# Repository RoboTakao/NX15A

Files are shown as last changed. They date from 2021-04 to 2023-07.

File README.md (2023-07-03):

# NX15A
Summary:  
http://robotakao.web.fc2.com/NX15/e/index.html  

[Key Controll]  
&emsp;When controlling with the keyboard.  
  
&emsp;M5Atom sketch : nx15_rosserial_wifi.ino  
  
&emsp;roslaunch nx15a nx15a_simulation_rosserial.launch  
&emsp;rosrun nx15a nx15a_walk_ik.py  
  
[Blynk Controll]  
&emsp;When controlling with the Blynk.  
  
&emsp;M5Atom sketch : nx15_rosserial_wifi_blynk_BT.ino  
  
&emsp;roslaunch nx15a nx15a_simulation_rosserial.launch  
&emsp;rosrun nx15a nx15a_walk_ik_blynk.py  
  
[Wii Nunchunck Controll]  
&emsp;When controlling with the Wii controller (M5Atom).  
&emsp;Use of IMU.  
  
&emsp;M5Atom sketch  
&emsp;&emsp;For robot : nx15_rosserial_wifi_IMU.ino  
&emsp;&emsp;For wii controller : nx15_rosserial_wifi_wii.ino  
  
&emsp;roslaunch nx15a nx15a_simulation_rosserial_wii_imu.launch  
&emsp;rosrun nx15a nx15a_walk_ik_wii_imu.py  
  
[Ultra Sonic Dinstance Sensor with Wii Nunchunck Controll]  
&emsp;Ultra Sonic Distance Sensor use.  
&emsp;When controlling with the Wii controller (M5Atom).  
  
&emsp;M5Atom sketch  
&emsp;&emsp;For robot : nx15_rosserial_wifi_IMU_Sonic.ino  
&emsp;&emsp;For wii controller : nx15_rosserial_wifi_wii.ino  
  
&emsp;roslaunch nx15a nx15a_simulation_rosserial_wii_imu.launch  
&emsp;rosrun nx15a nx15a_walk_ik_wii_imu_distancw.py

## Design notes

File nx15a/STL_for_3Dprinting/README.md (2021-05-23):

# NX15A
Summary:
http://robotakao.jp/NX15/e/index.html

These STL files are NX15 quadruped robot models.
This robot is under development. If you use these, please do so at your own risk.

d4.5 holes are for M3 insart nut.
d3 holes are for M2 insart nut.
d1.8 holes are for M2 tapping screw.

Body_Cover01.stl 1
Body_Cover02.stl 1
BoxBottom.stl 1
BoxFront.stl 1
BoxLeft.stl 1
BoxRear.stl 1
BoxRight.stl 1
Head_Cover.stl 1
Leg_part01.stl 2
Leg_part02.stl 2
Lever.stl 4
Plate01.stl 1
ServoBracket01.stl 2
ServoBracket02.stl 2
ServoBracket03.stl 4
ServoBracket04.stl 1
ServoBracket05.stl 1
ServoHornLever.stl 4
Spacer.stl 4
Stopper.stl 1
Tail_Cover.stl

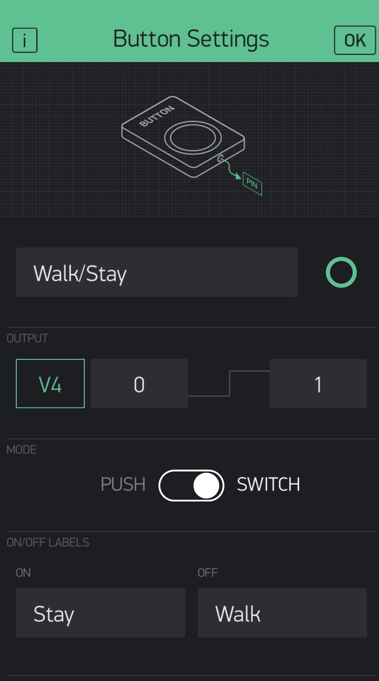
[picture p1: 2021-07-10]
nx15a/Blynk/Walk_Stay.jpeg

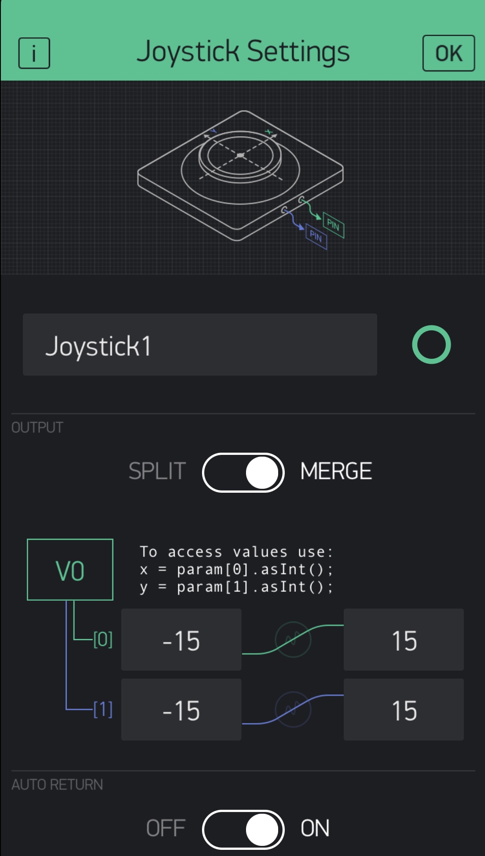
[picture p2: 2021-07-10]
nx15a/Blynk/Joystick1.jpeg

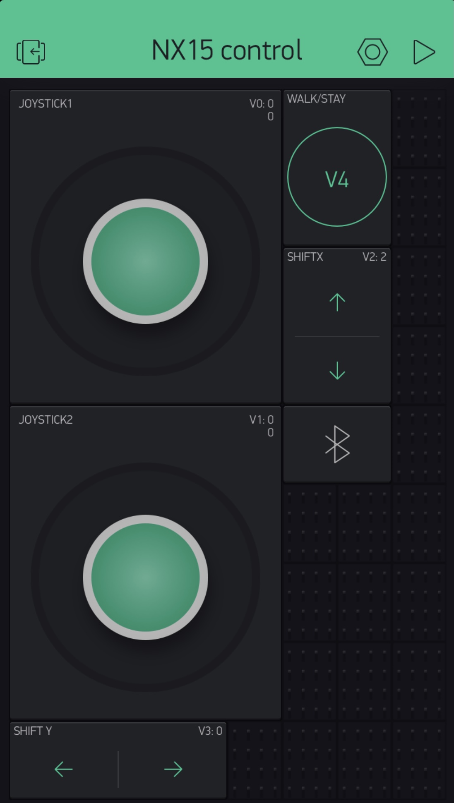
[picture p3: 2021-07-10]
nx15a/Blynk/Total.jpeg

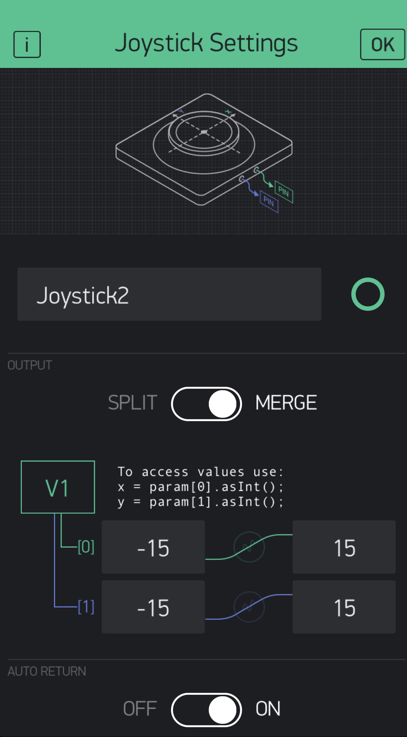
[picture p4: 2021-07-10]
nx15a/Blynk/Joystick2.jpeg

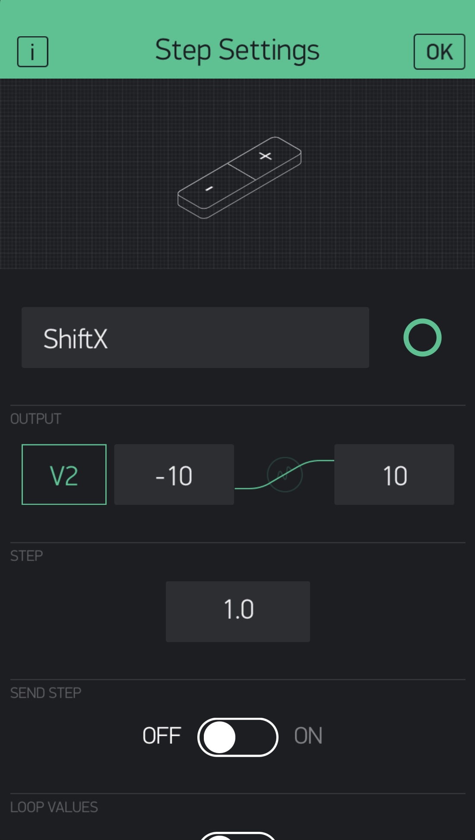
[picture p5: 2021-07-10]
nx15a/Blynk/ShiftX.jpeg

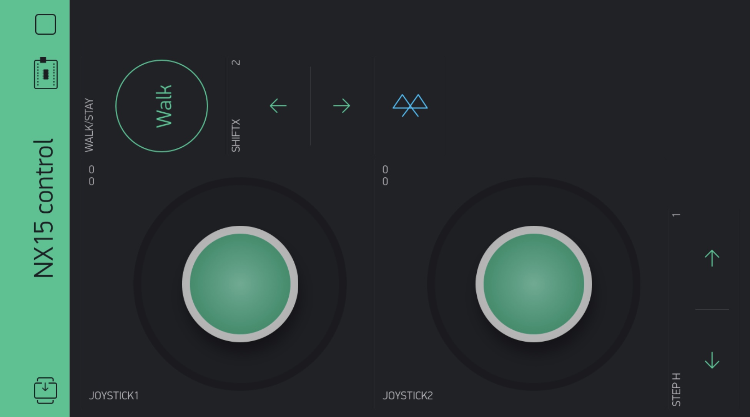
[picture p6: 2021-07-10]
nx15a/Blynk/NX15_controller.jpeg

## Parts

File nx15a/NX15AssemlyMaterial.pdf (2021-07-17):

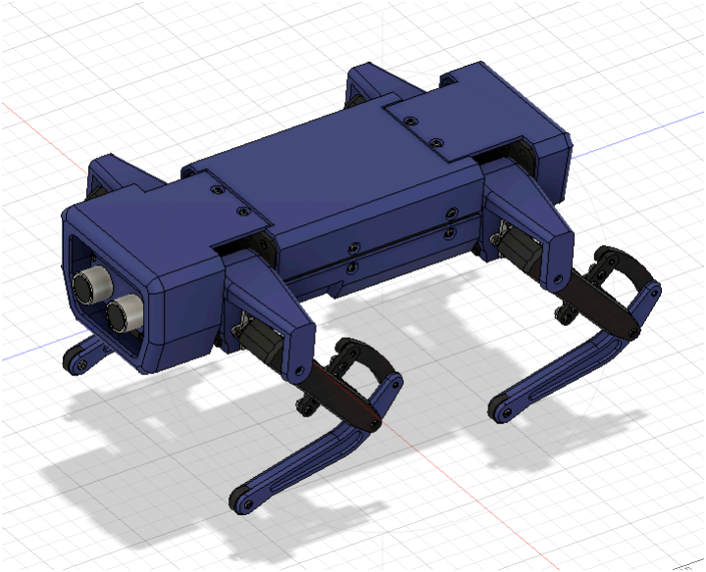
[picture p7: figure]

# Robo Takao 17.July.2021

# NX15 Quadruped Robot

# Assembly materials

# Leg Bottom (Left hand) x2

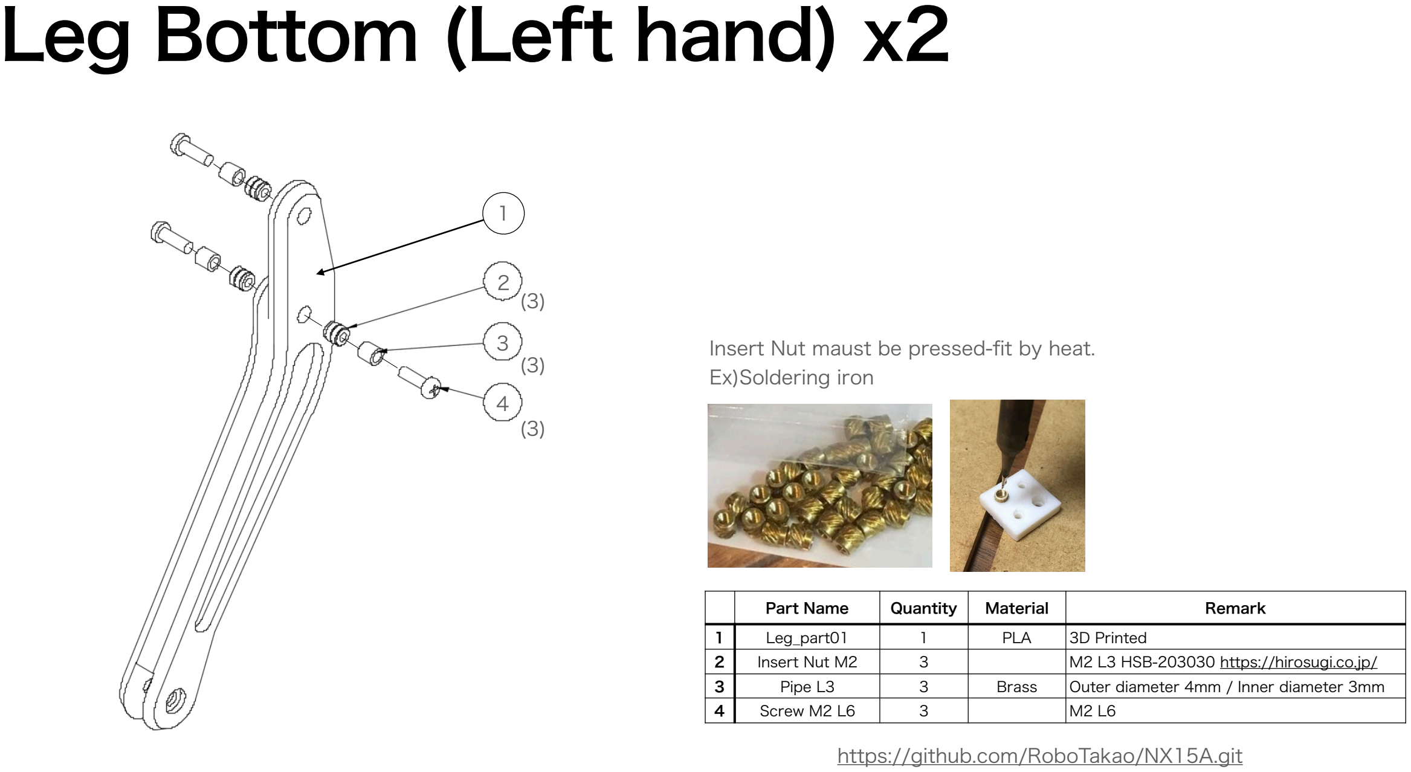
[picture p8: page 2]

| Part Name | Quantity | Material | Remark
1 | Leg_part01 | 1 | PLA | 3D Printed
2 | Insert Nut M2 | 3 | | M2 L3 HSB-203030 https://hirosugi.co.jp/
3 | Pipe L3 | 3 | Brass | Outer diameter 4mm / Inner diameter 3mm
4 | Screw M2 L6 | 3 | | M2 L6

1

2

3

4

## https://github.com/RoboTakao/NX15A.git

Insert Nut maust be pressed-fit by heat.

## Ex)Soldering iron

(3)

(3)

(3)

# Leg Bottom (Right hand) x2

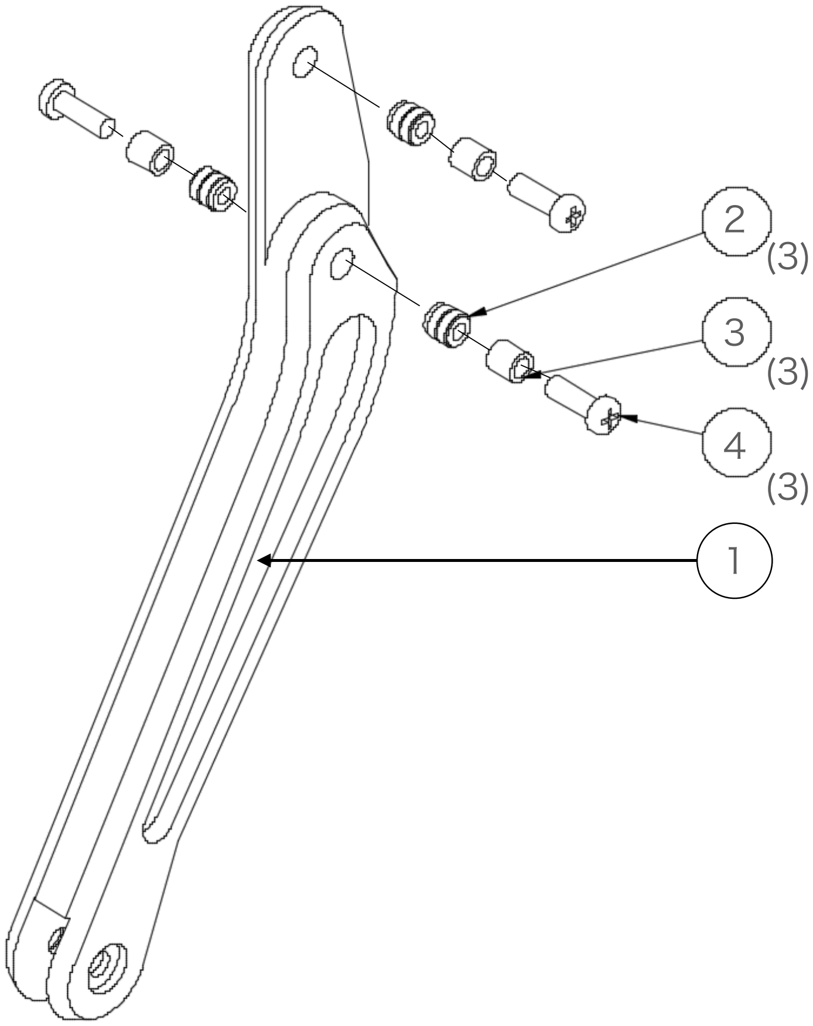
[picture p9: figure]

| Part Name | Quantity | Material | Remark
1 | Leg_part02 | 1 | PLA | 3D Printed
2 | Insert Nut M2 | 3 | | M2 L3 HSB-203030 https://hirosugi.co.jp/
3 | Pipe L3 | 3 | Brass | Outer diameter 4mm / Inner diameter 3mm
4 | Screw M2 L6 | 3 | | M2 L6

# Leg Middle x4

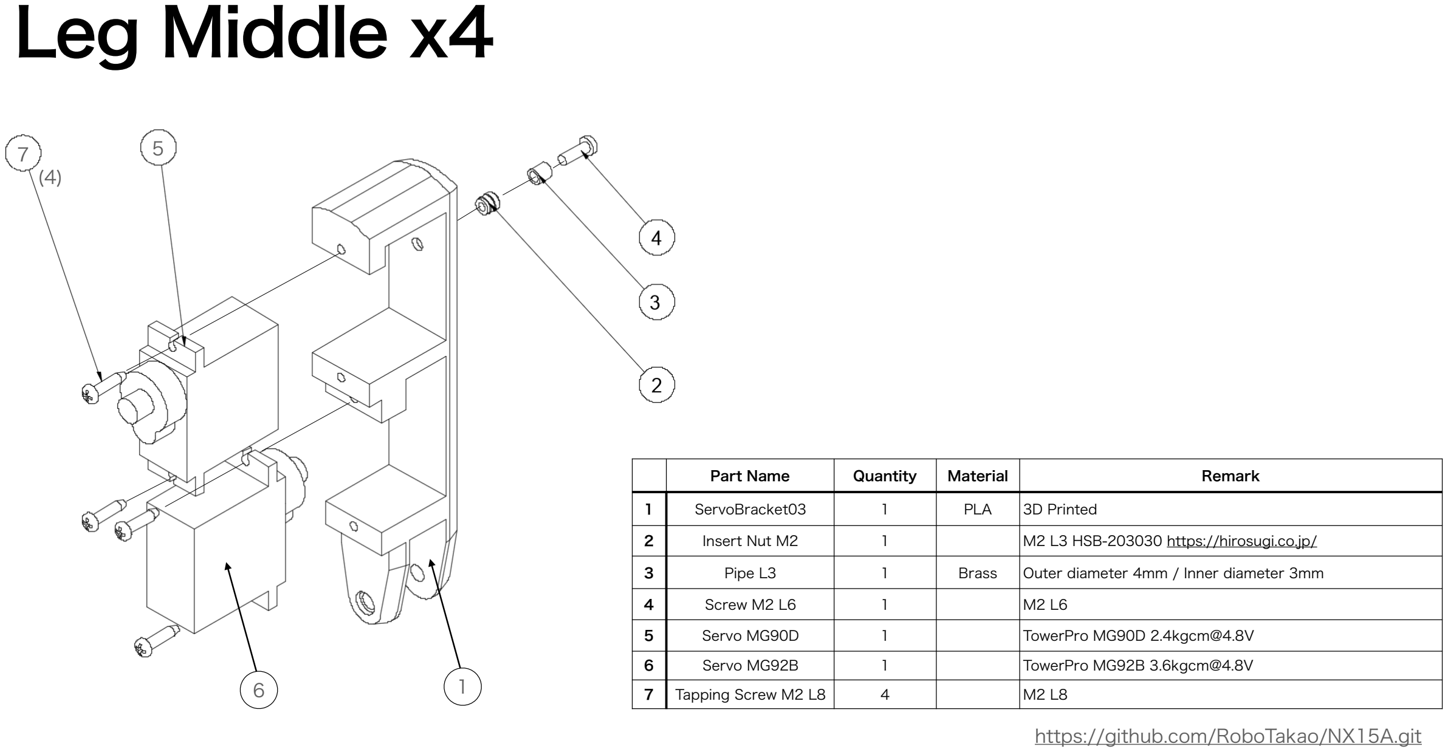
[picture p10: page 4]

1

5 7

6

| Part Name | Quantity | Material | Remark
1 | ServoBracket03 | 1 | PLA | 3D Printed
2 | Insert Nut M2 | 1 | | M2 L3 HSB-203030 https://hirosugi.co.jp/
3 | Pipe L3 | 1 | Brass | Outer diameter 4mm / Inner diameter 3mm
4 | Screw M2 L6 | 1 | | M2 L6
5 | Servo MG90D | 1 | | TowerPro MG90D 2.4kgcm@4.8V
6 | Servo MG92B | 1 | | TowerPro MG92B 3.6kgcm@4.8V
7 | Tapping Screw M2 L8 | 4 | | M2 L8

(4)

# Leg Upper (Left hand) x2

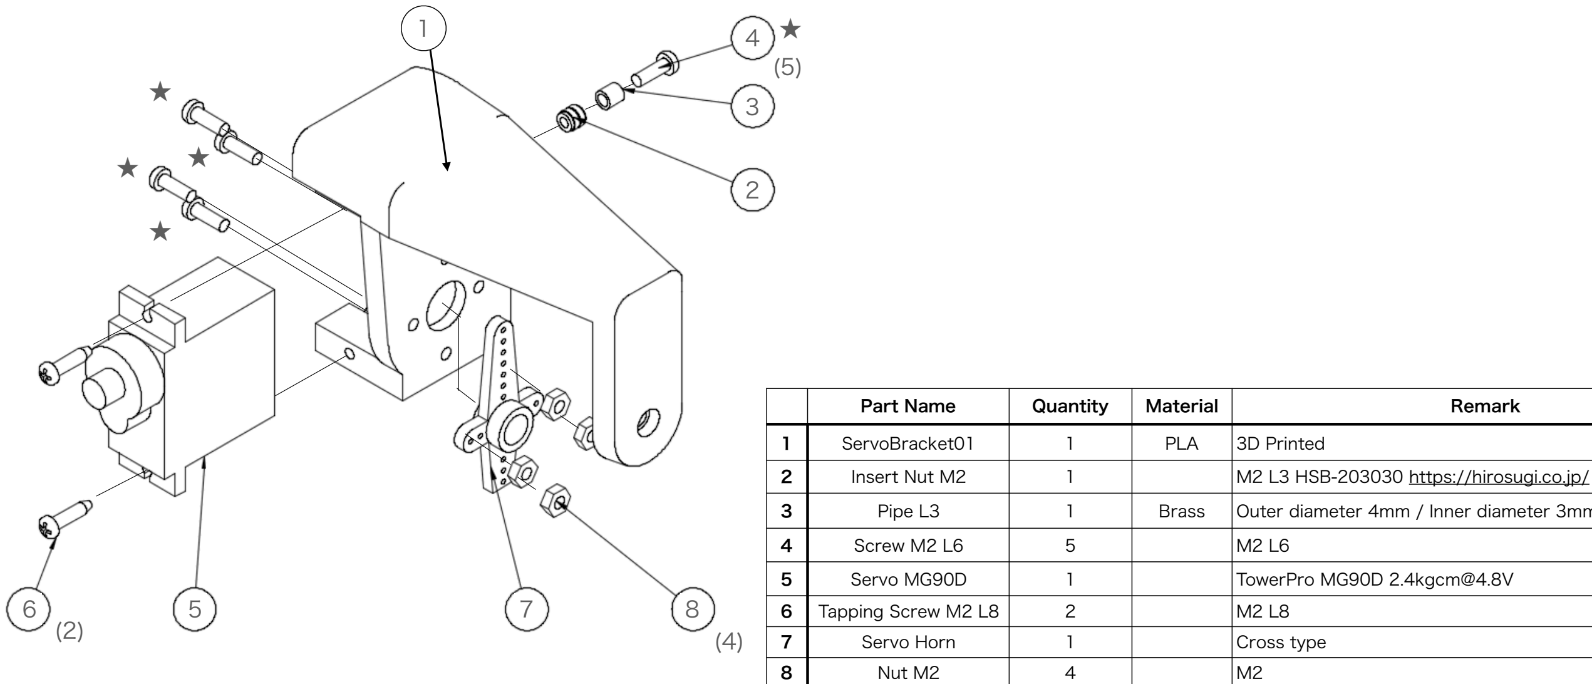
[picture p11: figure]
Part Name; Quantity; Material; Remark; ServoBracket01; PLA; 3D Printed; Insert Nut M2; M2 L3 HSB-203030 https://hirosugi.co.jp/; Screw M2 L6; Servo MG90D; TowerPro MG90D 2.4kgcm@4.8V; Tapping Screw M2 L8; Servo Horn; Cross type; Nut M2

3 | Pipe L3 | 1 | Brass | Outer diameter 4mm / Inner diameter 3mm

# Leg Upper (Right hand) x2

1

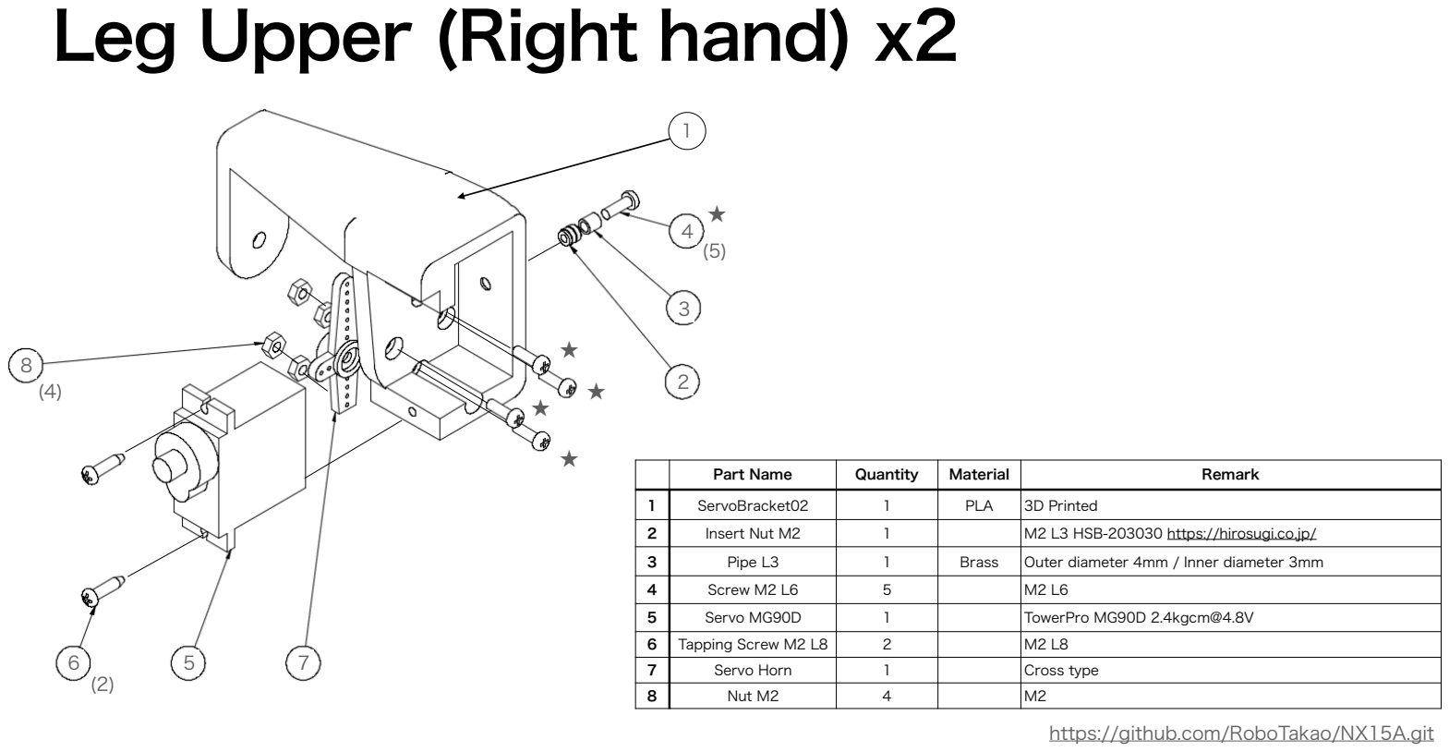
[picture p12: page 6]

| Part Name | Quantity | Material | Remark
1 | ServoBracket02 | 1 | PLA | 3D Printed
2 | Insert Nut M2 | 1 | | M2 L3 HSB-203030 https://hirosugi.co.jp/
3 | Pipe L3 | 1 | Brass | Outer diameter 4mm / Inner diameter 3mm
4 | Screw M2 L6 | 5 | | M2 L6
5 | Servo MG90D | 1 | | TowerPro MG90D 2.4kgcm@4.8V
6 | Tapping Screw M2 L8 | 2 | | M2 L8
7 | Servo Horn | 1 | | Cross type
8 | Nut M2 | 4 | | M2

2

3

4

★

★

★ ★

★

6 | 5 | 7

8

(5)

(2)

(4)

# Link Assʼy x4

3

2

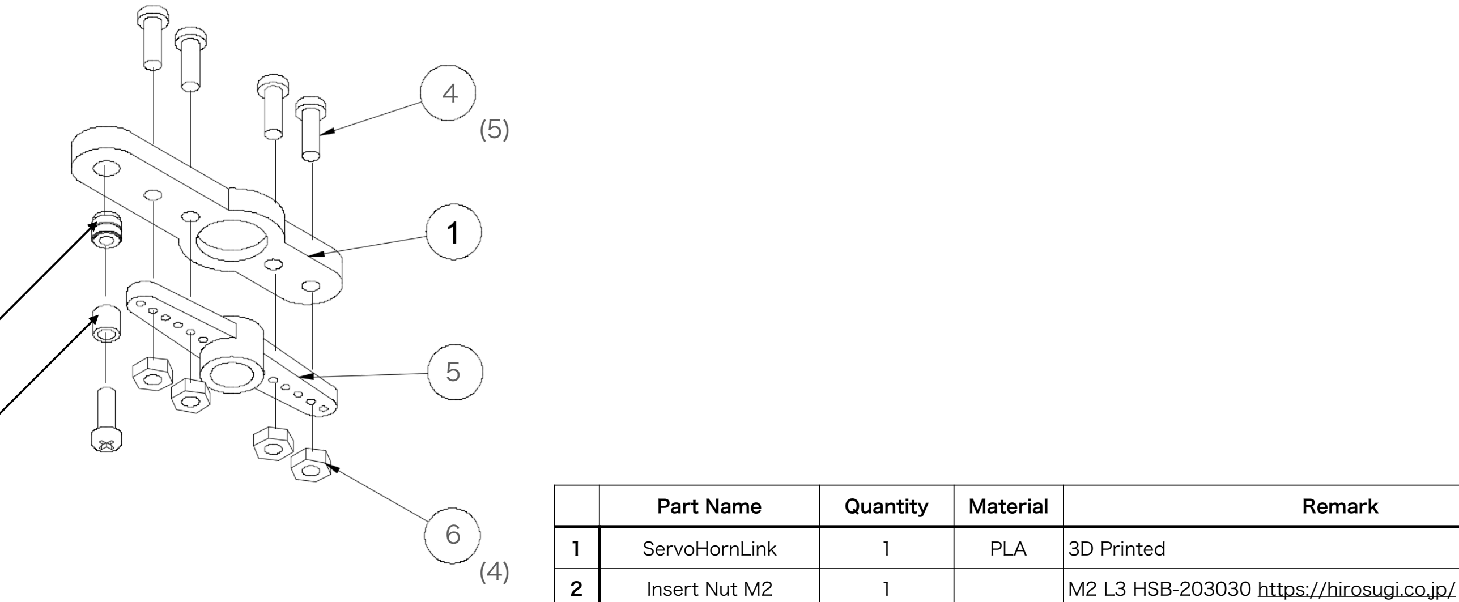
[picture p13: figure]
Part Name; Quantity; Material; Remark; ServoHornLink; PLA; 3D Printed; Insert Nut M2; M2 L3 HSB-203030 https://hirosugi.co.jp/

3 | Pipe L3 | 1 | Brass | Outer diameter 4mm / Inner diameter 3mm
4 | Screw M2 L6 | 5 | | M2 L6
5 | Servo Horn | 1
6 | Nut M2 | 4 | | M2

# Leg Assʼy (Left hand) x2

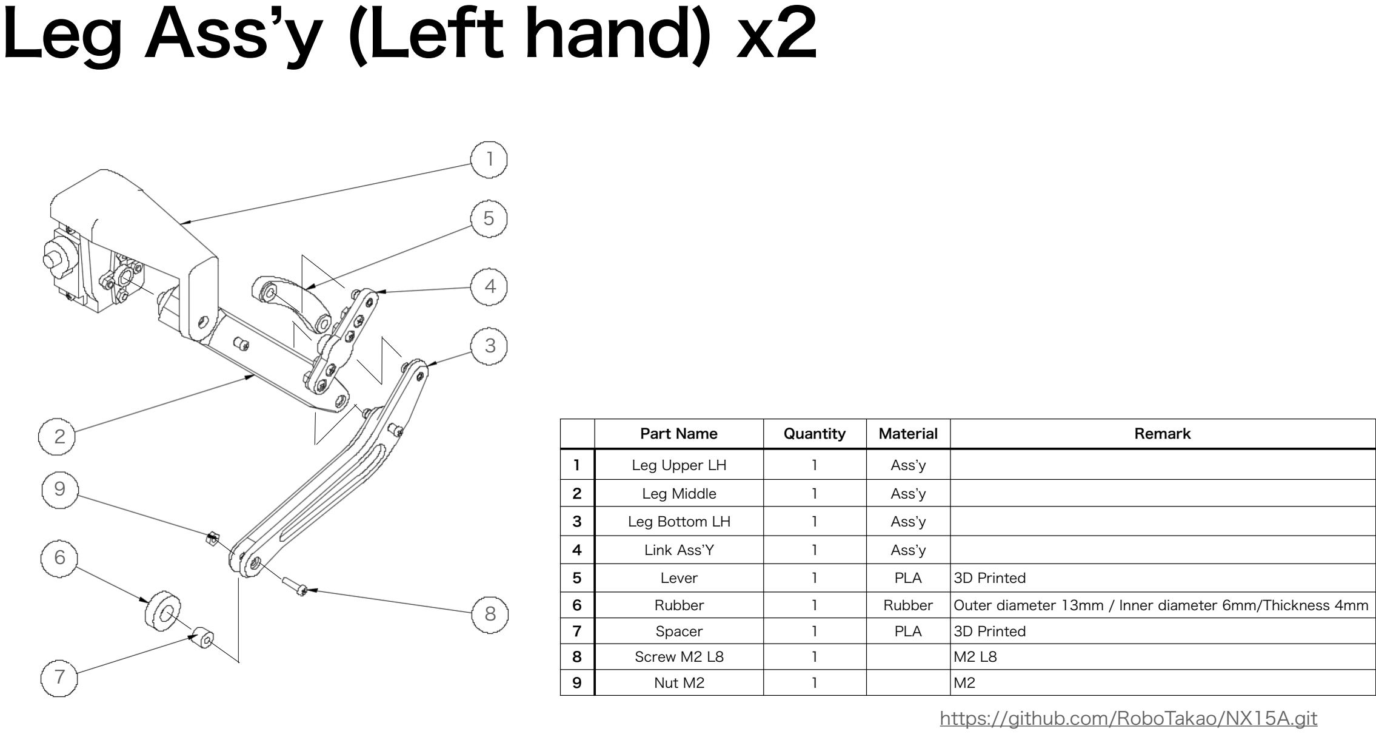
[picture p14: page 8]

| Part Name | Quantity | Material | Remark
1 | Leg Upper LH | 1 | Assʼy
2 | Leg Middle | 1 | Assʼy
3 | Leg Bottom LH | 1 | Assʼy
4 | Link AssʼY | 1 | Assʼy
5 | Lever | 1 | PLA | 3D Printed
6 | Rubber | 1 | Rubber | Outer diameter 13mm / Inner diameter 6mm/Thickness 4mm
7 | Spacer | 1 | PLA | 3D Printed
8 | Screw M2 L8 | 1 | | M2 L8
9 | Nut M2 | 1 | | M2

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
# Leg Assʼy (Right hand) x2

4


| Part Name | Quantity | Material | Remark
1 | Leg Upper RH | 1 | Assʼy
2 | Leg Middle | 1 | Assʼy
3 | Leg Bottom RH | 1 | Assʼy
4 | Link AssʼY | 1 | Assʼy
5 | Lever | 1 | PLA | 3D Printed
6 | Rubber | 1 | Rubber | Outer diameter 13mm / Inner diameter 6mm/Thickness 4mm
7 | Spacer | 1 | PLA | 3D Printed
8 | Screw M2 L8 | 1 | | M2 L8
9 | Nut M2 | 1 | | M2

3

5

6

7

8

9

# Front Bracket


| Part Name | Quantity | Material | Remark
1 | ServoBracket04 | 1 | PLA | 3D Printed
2 | Insert Nut M2 | 4 | | M2 L3 HSB-203030 https://hirosugi.co.jp/

2

1

(4)

# Rear Bracket


| Part Name | Quantity | Material | Remark
1 | ServoBracket04 | 1 | PLA | 3D Printed
2 | Insert Nut M2 | 4 | | M2 L3 HSB-203030 https://hirosugi.co.jp/

2

1

(4)

# Body Box

★


| Part Name | Quantity | Material | Remark
1 | BoxBottom | 1 | PLA | 3D Printed
2 | BoxFront | 1 | PLA | 3D Printed
3 | BoxRear | 1 | PLA | 3D Printed
4 | BoxRight | 1 | PLA | 3D Printed
5 | BoxLeft | 1 | PLA | 3D Printed
6 | Insert Nut M2 | 16 | | M2 L3 HSB-203030 https://hirosugi.co.jp/
7 | Tapping Screw M2 L6 | 12 | | M2 L6

1

2

3 | 4

5

7 | ★ | 6

★
★ | ★ ★

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
(12) (16)

# Sensor Brakcet


| Part Name | Quantity | Material | Remark
1 | Plate01 | 1 | PLA | 3D Printed
2 | Insert Nut M3 | 2 | | M3 L3 HSB-304530 https://hirosugi.co.jp/

# Leg Assemblies

2 | 3 | 4


| Part Name | Quantity | Material | Remark
1 | Leg Assʼy LH | 1 | Assʼy
2 | Leg Assʼy RH | 1 | Assʼy
3 | Front Bracket | 1 | Assʼy
4 | Rear Bracket | 1 | Assʼy
5 | Servo Horn | 4 | | Cross type
6 | Screw M2 L6 | 16 | | M2 L6
7 | Nut M2 | 16 | | M

1

6 | 5 | 7
(16) | (4) | (16)

# Box Assembly

3


| Part Name | Quantity | Material | Remark
1 | Body Box | 1 | Assʼy
2 | PCA9685 | 1 | | Servo Drvier
3 | Tapping Screw M2 L6 | 6
4 | Printed Card 01 | 1 | | Power Supply
5 | Tapping Screw M2 L8 | 4
6 | Pipe L3 | 4 | Brass | Outer diameter 4mm / Inner diameter 3mm
7 | Battery | 1 | | NiMH 6V
8 | Stopper | 1 | PLA | 3D Printed
9 | Switch | 1
10 | Screw M2 L8 | 2 | | M2 L8
11 | Nut M2 | 2 | | M2
1 | 7

8

2

4

5

6

9 | 11

★

★

★

★

★

10 | ★

(6)

(4)

(4)

(2) (2)

# Top Assembly

10


Part Name | Quantity | Material | Remark

1 | Body Assʼy | 1 | Assʼy
2 | Leg Assemblies | 1 | Assʼy
3 | Cap screw M2 L6 | 8 | | M2 L6
4 | Sensor Bracket | 1 | Assʼy
5 | Tapping Screw M2 L6 | 4
6 | M5Camera | 1
7 | Screw M3 L10 | 2 | | M3 L10
8 | HC-SRO4 | 1 | | Sonic Distance Sensor
9 | Printed Card 02 | 1 | | For M5Atom
10 | Tapping Screw M2 L8 | 8 | | M2 L8
11 | Pipe L3 | 4 | Brass | Outer diameter 4mm / Inner diameter 3mm
12 | M5Atom Matrix | 1 | | M5Atom Matrix
13 | Head Cover | 1 | PLA | 3D Printed
14 | Tapping Screw M2 L5 | 16 | | M2 M5
15 | Tail Cover | 1 | PLA | 3D Printed
16 | Body Cover 01 | 1 | PLA | 3D Printed
17 | Body Cover 02 | 1 | PLA | 3D

# Connection


# Completed


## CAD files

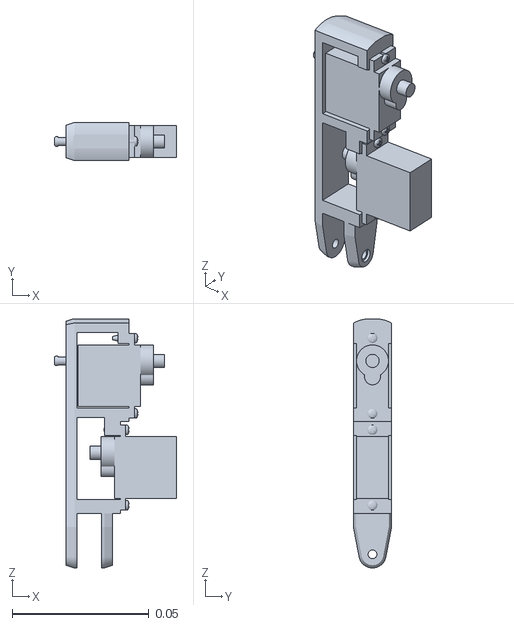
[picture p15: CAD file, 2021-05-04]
nx15a/stl/Leg_Mid_RH.stl
0.0447 x 0.014 x 0.0912

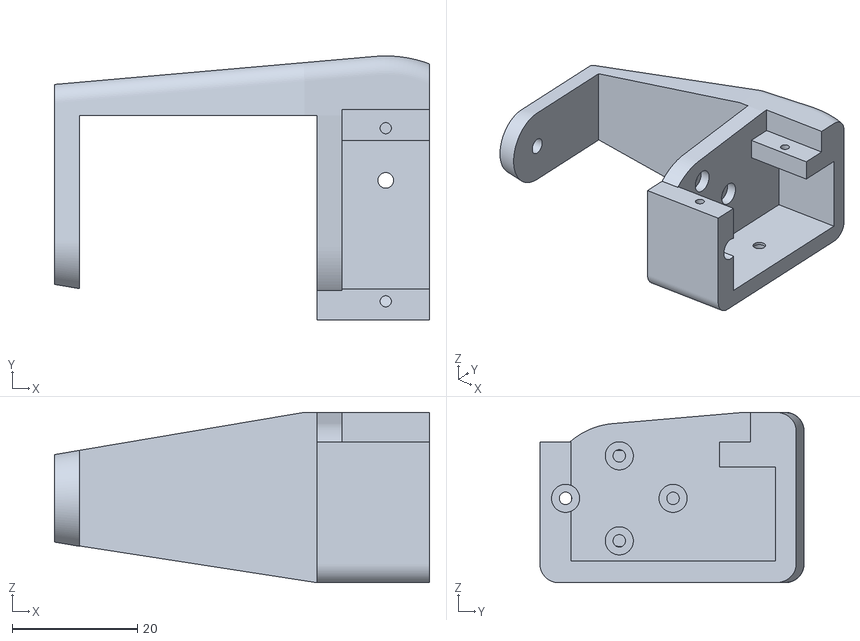
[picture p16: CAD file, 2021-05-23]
nx15a/STL_for_3Dprinting/ServoBracket02.stl
60.0 x 42.3 x 27.3

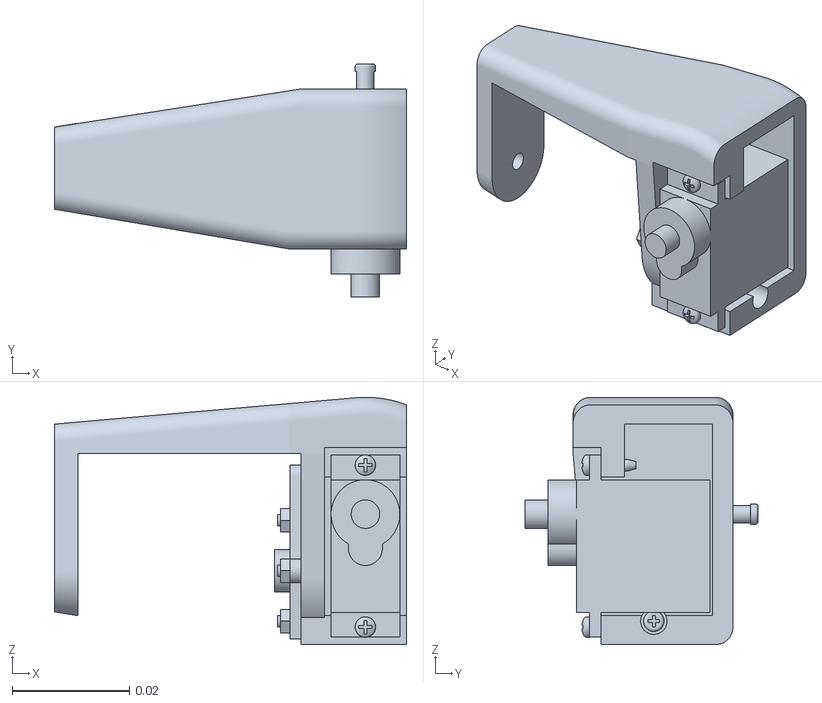
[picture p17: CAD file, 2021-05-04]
nx15a/stl/Leg_Upper_RH.stl
0.06 x 0.0398 x 0.0422

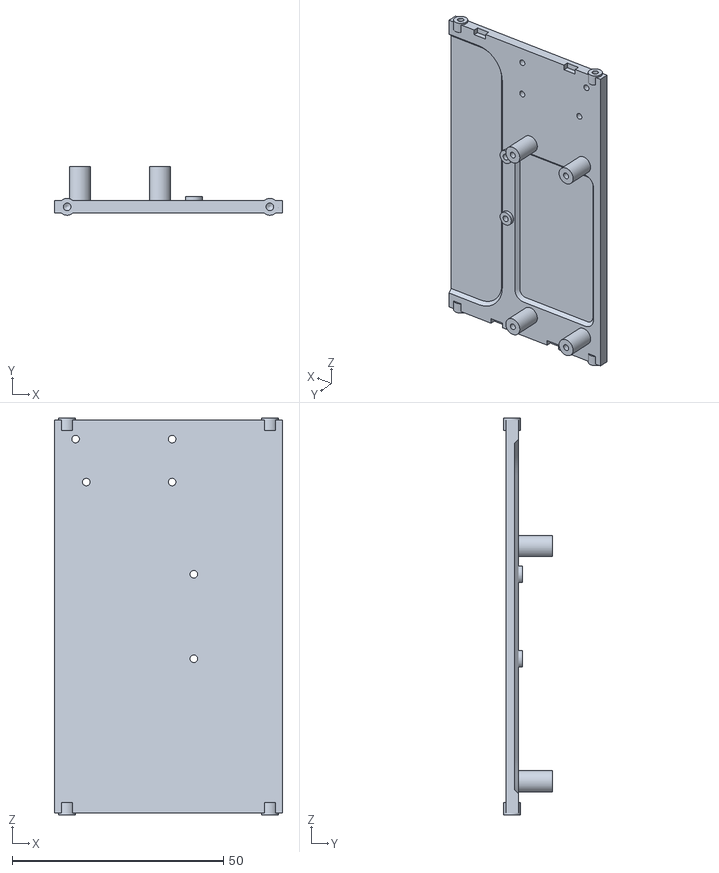
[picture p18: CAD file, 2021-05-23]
nx15a/STL_for_3Dprinting/BoxBottom.stl
54.0 x 11.5 x 94.0

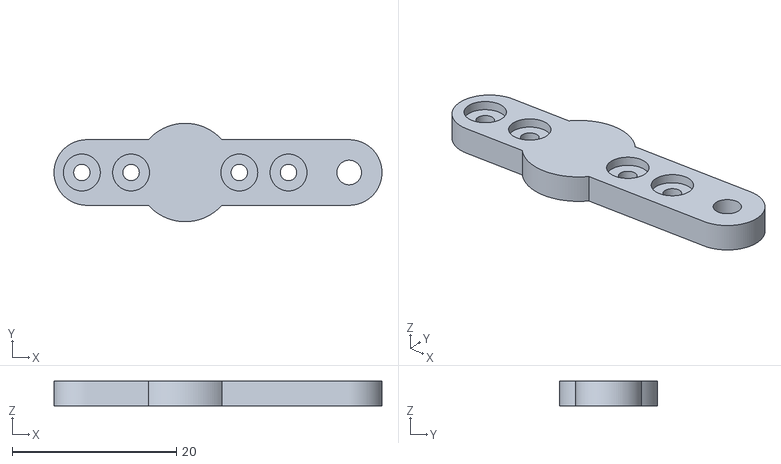
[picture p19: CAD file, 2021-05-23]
nx15a/STL_for_3Dprinting/ServoHornLever.stl
40.0 x 12.0 x 3.00

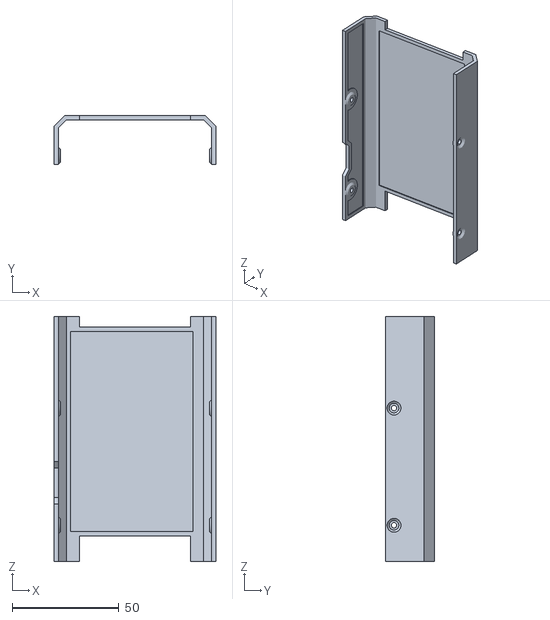
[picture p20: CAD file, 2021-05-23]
nx15a/STL_for_3Dprinting/Body_Cover01.stl
76.0 x 23.0 x 115.0

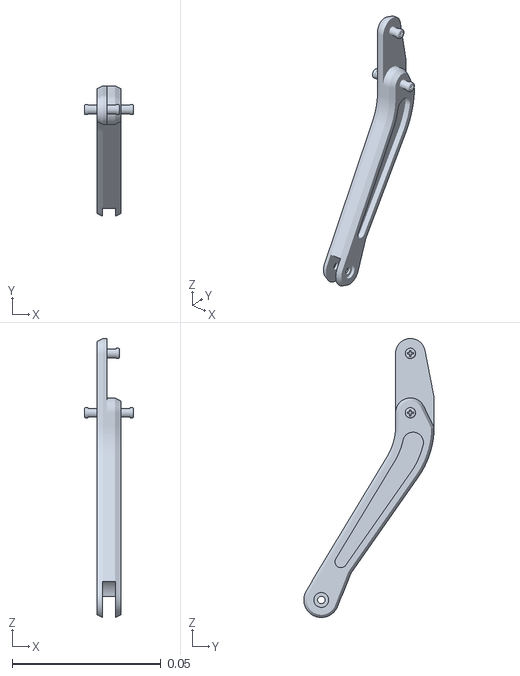
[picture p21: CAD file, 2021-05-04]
nx15a/stl/Leg_bottom_RH.stl
0.0166 x 0.0439 x 0.0939

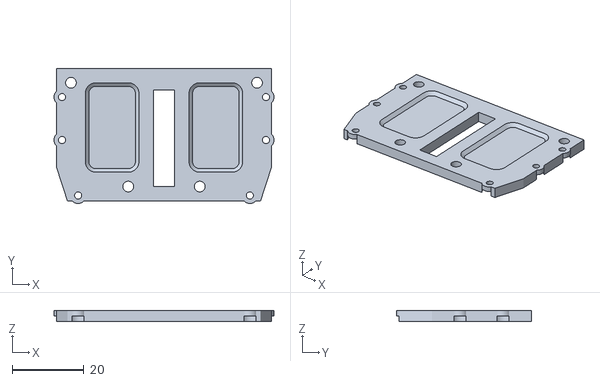
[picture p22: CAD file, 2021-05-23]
nx15a/STL_for_3Dprinting/BoxFront.stl
61.5 x 37.7 x 3.00

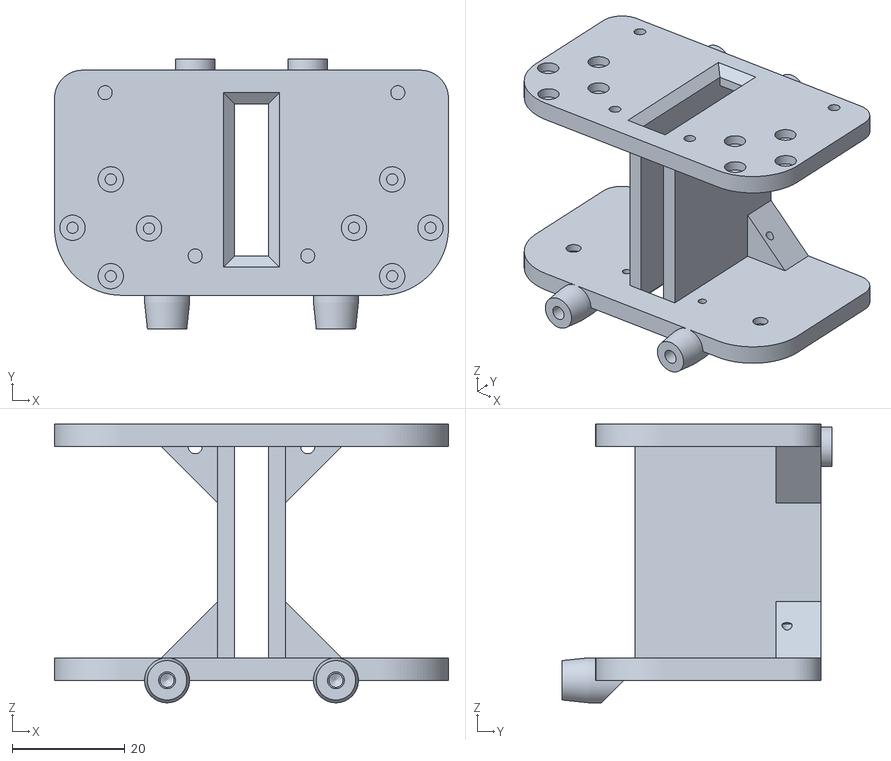
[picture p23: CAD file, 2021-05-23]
nx15a/STL_for_3Dprinting/ServoBracket05.stl
70.0 x 48.0 x 49.5

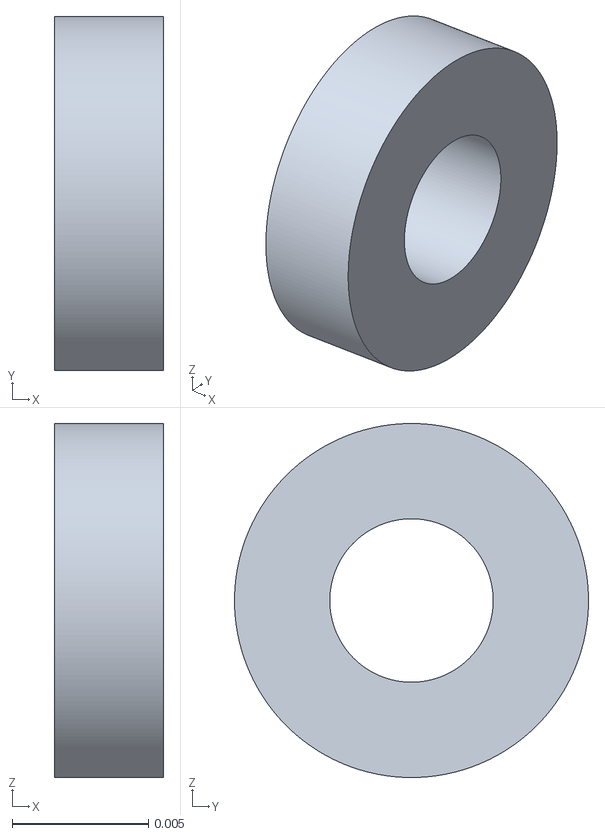
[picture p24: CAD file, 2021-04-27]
nx15a/stl/Rubber.stl
0.004 x 0.013 x 0.013

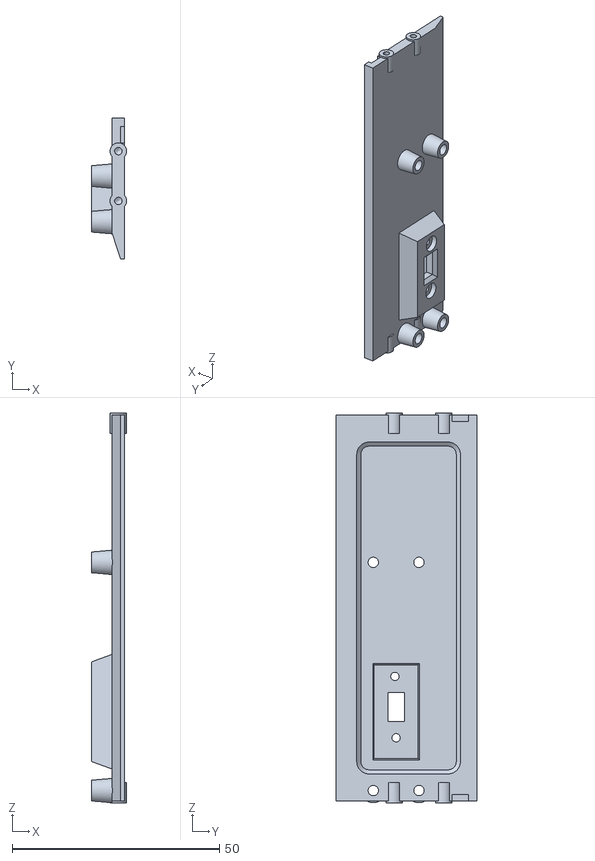
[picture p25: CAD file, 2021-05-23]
nx15a/STL_for_3Dprinting/BoxLeft.stl
8.50 x 34.0 x 94.0

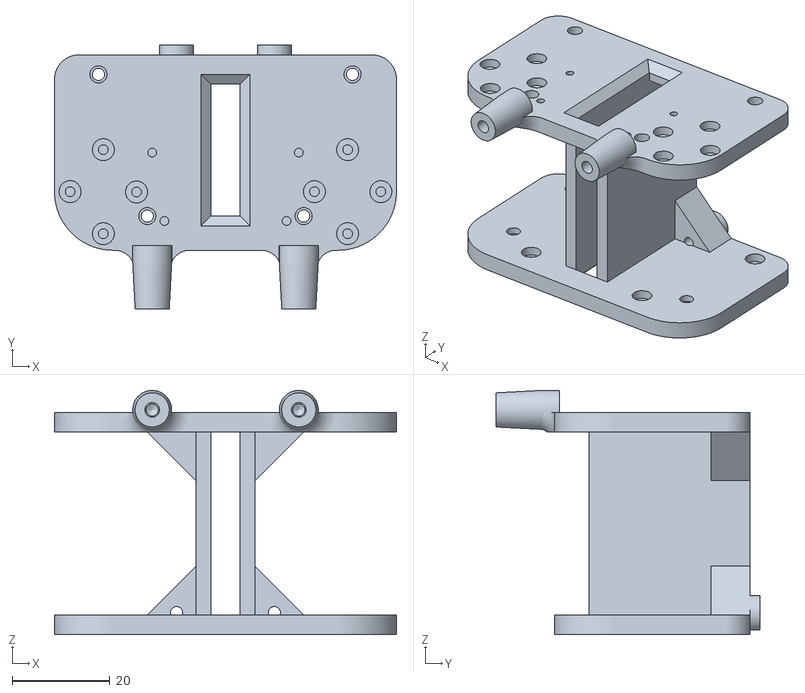
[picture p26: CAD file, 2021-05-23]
nx15a/STL_for_3Dprinting/ServoBracket04.stl
70.0 x 54.0 x 50.0

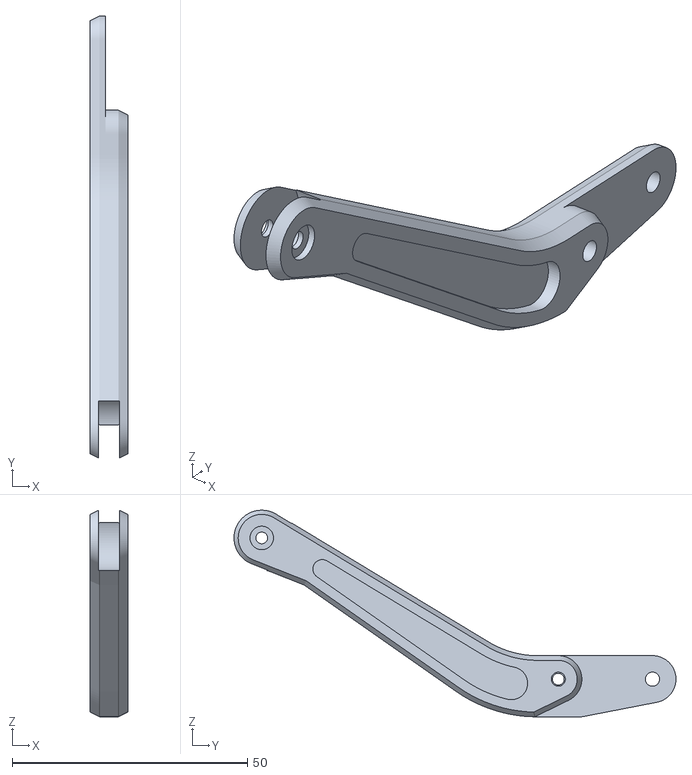
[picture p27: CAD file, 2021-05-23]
nx15a/STL_for_3Dprinting/Leg_part02.stl
8.00 x 93.9 x 43.9

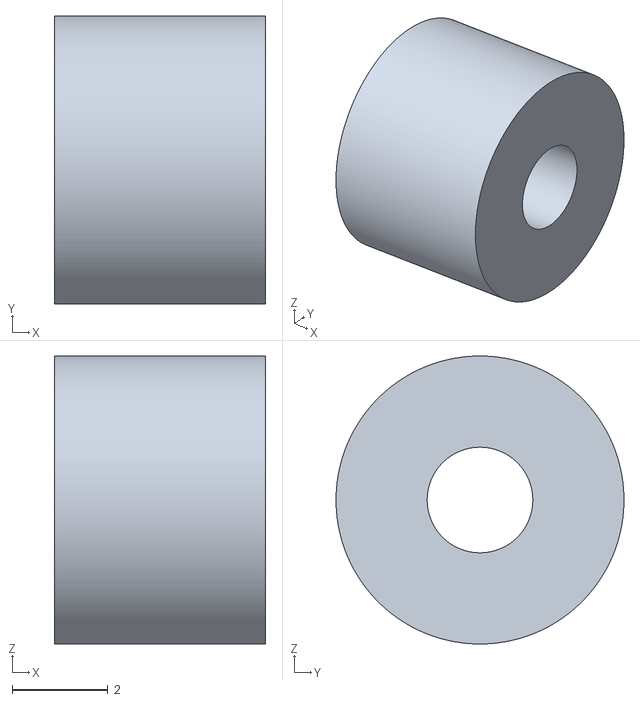
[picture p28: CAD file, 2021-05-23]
nx15a/STL_for_3Dprinting/Spacer.stl
4.40 x 6.00 x 6.00

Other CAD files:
nx15a/stl/Leg_Upper_LH.stl
nx15a/stl/Leg_Mid_LH.stl
nx15a/stl/Leg_bottom_LH.stl
nx15a/STL_for_3Dprinting/Body_Cover02.stl
nx15a/STL_for_3Dprinting/BoxRear.stl
nx15a/STL_for_3Dprinting/BoxRight.stl
nx15a/STL_for_3Dprinting/Head_Cover.stl
nx15a/STL_for_3Dprinting/Leg_part01.stl
nx15a/STL_for_3Dprinting/Lever.stl
nx15a/STL_for_3Dprinting/Plate01.stl
nx15a/STL_for_3Dprinting/ServoBracket01.stl
nx15a/STL_for_3Dprinting/ServoBracket03.stl
nx15a/STL_for_3Dprinting/Stopper.stl
nx15a/STL_for_3Dprinting/Tail_Cover.stl

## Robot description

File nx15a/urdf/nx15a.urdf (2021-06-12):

<?xml version="1.0" ?>
<robot name="nx15a">
    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
    <link name="base_link" />
    <joint name="base_joint" type="fixed">
        <parent link="base_link" />
        <child link="Body" />
        <origin xyz="0 0 0.140" rpy="0 0 0" />
    </joint>
    <link name="Body">
        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
	<inertial>
            <origin xyz="0 0.052 0.008" rpy="0 0 0" />
            <mass value="0.345" />
            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
        </inertial>
    </link>
    <joint name="joint_LF_1" type="revolute">
        <parent link="Body" />
        <child link="Leg_Upper_LF" />
        <origin xyz="0.025 -0.0366 0" rpy="0 0 0" />
        <axis xyz="0 1 0" />
        <limit lower="-1.57" upper="1.57" effort="30" velocity="3.142" />
    </joint>
    <link name="Leg_Upper_LF">
        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
	<inertial>
            <origin xyz="0.00923 0.0212 0.0000" rpy="0 0 0" />
            <mass value="0.0343" />
            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
        </inertial>
    </link>
    <joint name="joint_LF_2" type="revolute">
        <parent link="Leg_Upper_LF" />
        <child link="Leg_Mid_LF" />
        <origin xyz="0.0119 0.022 -0.00965" rpy="0.785398163397 0 0" />
        <axis xyz="1 0 0" />
        <limit lower="-1.57" upper="1.57" effort="30" velocity="3.142" />
    </joint>
    <link name="Leg_Mid_LF">
        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
	<inertial>
            <origin xyz="0.0175 0 -0.0229" rpy="0 0 0" />
            <mass value="0.0389" />
            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
        </inertial>
    </link>
    <joint name="joint_LF_3" type="revolute">
        <parent link="Leg_Mid_LF" />
        <child link="Leg_bottom_LF" />
        <origin xyz="0.023 0 -0.07085" rpy="-1.570796326795 0 0" />
        <axis xyz="1 0 0" />
        <limit lower="-1.57" upper="1.57" effort="30" velocity="3.142" />
    </joint>
    <link name="Leg_bottom_LF">
        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
	<inertial>
            <origin xyz="0.0049 -0.012896 -0.030" rpy="-0.444360827558 0 0" />
            <mass value="0.00773" />
            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
        </inertial>
    </link>
    <joint name="joint_LF_4" type="fixed">
        <parent link="Leg_bottom_LF" />
        <child link="Rubber_LF" />
        <origin xyz="0.0023 -0.030 -0.063" rpy="0.785398163397 0 0" />
    </joint>
    <link name="Rubber_LF">
        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
	<inertial>
            <origin xyz="0.0022 0 0" rpy="0 0 0" />
            <mass value="0.0004" />
            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
        </inertial>
    </link>
    
    <joint name="joint_LR_1" type="revolute">
        <parent link="Body" />
        <child link="Leg_Upper_LR" />
        <origin xyz="0.025 0.1089 0" rpy="0 0 0" />
        <axis xyz="0 1 0" />
        <limit lower="-1.57" upper="1.57" effort="30" velocity="3.142" />
    </joint>
    <link name="Leg_Upper_LR">
        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
	<inertial>
            <origin xyz="0.00923 0.0212 0.0000" rpy="0 0 0" />
            <mass value="0.0343" />
            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
        </inertial>
    </link>
    <joint name="joint_LR_2" type="revolute">
        <parent link="Leg_Upper_LR" />
        <child link="Leg_Mid_LR" />
        <origin xyz="0.0119 0.022 -0.00965" rpy="0.785398163397 0 0" />
        <axis xyz="1 0 0" />
        <limit lower="-1.57" upper="1.57" effort="30" velocity="3.142" />
    </joint>
    <link name="Leg_Mid_LR">
        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
	<inertial>
            <origin xyz="0.0175 0 -0.0229" rpy="0 0 0" />
            <mass value="0.0389" />
            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
        </inertial>
    </link>
    <joint name="joint_LR_3" type="revolute">
        <parent link="Leg_Mid_LR" />
        <child link="Leg_bottom_LR" />
        <origin xyz="0.023 0 -0.07085" rpy="-1.570796326795 0 0" />
        <axis xyz="1 0 0" />
        <limit lower="-1.57" upper="1.57" effort="30" velocity="3.142" />
    </joint>
    <link name="Leg_bottom_LR">
        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
	<inertial>
            <origin xyz="0.0049 -0.012896 -0.030" rpy="-0.444360827558 0 0" />
            <mass value="0.00773" />
            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
        </inertial>
    </link>
    <joint name="joint_LR_4" type="fixed">
        <parent link="Leg_bottom_LR" />
        <child link="Rubber_LR" />
        <origin xyz="0.0023 -0.030 -0.063" rpy="0.785398163397 0 0" />
    </joint>
    <link name="Rubber_LR">
        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
	<inertial>
            <origin xyz="0.0022 0 0" rpy="0 0 0" />
            <mass value="0.0004" />
            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
        </inertial>
    </link>

    <joint name="joint_RF_1" type="revolute">
        <parent link="Body" />
        <child link="Leg_Upper_RF" />
        <origin xyz="-0.025 -0.0366 0" rpy="0 0 0" />
        <axis xyz="0 1 0" />
        <limit lower="-1.57" upper="1.57" effort="30" velocity="3.142" />
    </joint>
    <link name="Leg_Upper_RF">
        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
	<inertial>
            <origin xyz="-0.00923 0.0212 0.0000" rpy="0 0 0" />
            <mass value="0.0343" />
            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
        </inertial>
    </link>
    <joint name="joint_RF_2" type="revolute">
        <parent link="Leg_Upper_RF" />
        <child link="Leg_Mid_RF" />
        <origin xyz="-0.0119 0.022 -0.00965" rpy="0.785398163397 0 0" />
        <axis xyz="1 0 0" />
        <limit lower="-1.57" upper="1.57" effort="30" velocity="3.142" />
    </joint>
    <link name="Leg_Mid_RF">
        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
	<inertial>
            <origin xyz="-0.0175 0 -0.0229" rpy="0 0 0" />
            <mass value="0.0389" />
            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
        </inertial>
    </link>
    <joint name="joint_RF_3" type="revolute">
        <parent link="Leg_Mid_RF" />
        <child link="Leg_bottom_RF" />
        <origin xyz="-0.023 0 -0.07085" rpy="-1.570796326795 0 0" />
        <axis xyz="1 0 0" />
        <limit lower="-1.57" upper="1.57" effort="30" velocity="3.142" />
    </joint>
    <link name="Leg_bottom_RF">
        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
	<inertial>
            <origin xyz="-0.0049 -0.012896 -0.030" rpy="-0.444360827558 0 0" />
            <mass value="0.00773" />
            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
        </inertial>
    </link>
    <joint name="joint_RF_4" type="fixed">
        <parent link="Leg_bottom_RF" />
        <child link="Rubber_RF" />
        <origin xyz="-0.0023 -0.030 -0.063" rpy="0.785398163397 0 0" />
    </joint>
    <link name="Rubber_RF">
        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
	<inertial>
            <origin xyz="-0.0022 0 0" rpy="0 0 0" />
            <mass value="0.0004" />
            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
        </inertial>
    </link>
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

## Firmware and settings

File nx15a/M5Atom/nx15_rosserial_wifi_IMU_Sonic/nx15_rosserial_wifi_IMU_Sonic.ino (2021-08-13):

#include "M5Atom.h"
#include <Wire.h>          // I2C setting
#include <PCA9685.h>       //for PCA9685
#include <ros.h>
#include <std_msgs/Int32.h>
#include <std_msgs/Int32MultiArray.h>
#include <sensor_msgs/JointState.h>
#include <WiFi.h>

//Sonic Sensor
#define echo 33 // Echo Pin
#define trig 23 // Trig Pin
double Duration = 0; //recieved duration
double Distance = 0; //distance


//Input address if PCA9685
PCA9685 pwm = PCA9685(0x40);

#define SERVOMIN 104            //Min pulse width (12bit 500μs) 
#define SERVOMAX 512            //Max pulse width (12bit 2500μs) 

float cont_min = -1570;
float cont_max = 1570;
int SrvAng[12] = {4914, 4914, 4914, 4914, 4914, 4914, 4914, 4914, 4914, 4914, 4914, 4914}; //90deg
float TARGET_JOINT_POSITIONS[12] = {0.0, 0.0, 0.0, 0.0, 0.0, 0.0, 0.0, 0.0, 0.0, 0.0, 0.0, 0.0};
float TRIM[12] = {0.03, -0.07, -0.16, 0.03, -0.05, -0.03, -0.03, 0.1, 0.0, 0.07, 0.12, -0.12};
int target_angle[12];

const char* ssid = "XXXXXXXXXXXXXXXXXXXX";
const char* password = "XXXXXXXXXXXXXXXXXXXXX";

WiFiClient client;
IPAddress server(192, 168, 10, 19); //ROS core IP adress

//IMU
float roll, pitch, yaw;
#define IMU_AFS M5.IMU.AFS_2G       // Ascale [g]      (±2,4,8,16)
#define IMU_GFS M5.IMU.GFS_250DPS  // Gscale [deg/s]  (±250,500,1000,200)
int roll_initial, pitch_initial, yaw_initial;
int initial_count = 100;

class WiFiHardware {
  public:
    WiFiHardware() {};
    void init() {
      client.connect(server, 11411);
    }
    int read() {
      return client.read();
    }
    void write(uint8_t* data, int length) {
      for (int i = 0; i < length; i++)
        client.write(data[i]);
    }
    unsigned long time() {
      return millis(); // easy; did this one for you
    }
};

ros::NodeHandle_<WiFiHardware> nh;

std_msgs::Int32MultiArray IMU_Distance_data;

void servo_cb(const sensor_msgs::JointState& msg) {

  TARGET_JOINT_POSITIONS[0] = msg.position[6]; //FrontRight
  TARGET_JOINT_POSITIONS[1] = -msg.position[7]; //FrontRight
  TARGET_JOINT_POSITIONS[2] = -msg.position[8]; //FrontRight
  TARGET_JOINT_POSITIONS[3] = msg.position[0]; //FrontLeft
  TARGET_JOINT_POSITIONS[4] = msg.position[1]; //FrontLeft
  TARGET_JOINT_POSITIONS[5] = msg.position[2]; //FrontLeft
  TARGET_JOINT_POSITIONS[6] = msg.position[9]; //RearRight
  TARGET_JOINT_POSITIONS[7] = -msg.position[10]; //RearRight
  TARGET_JOINT_POSITIONS[8] = -msg.position[11]; //RearRight
  TARGET_JOINT_POSITIONS[9] = msg.position[3]; //RearLeft
  TARGET_JOINT_POSITIONS[10] = msg.position[4]; //RearLeft
  TARGET_JOINT_POSITIONS[11] = msg.position[5]; //RearLeft

  servo_set();

}

ros::Subscriber<sensor_msgs::JointState> sub("joint_states", servo_cb);
ros::Publisher IMU_Distance_chatter("IMU_Distance_data", &IMU_Distance_data);

void setupWiFi() {
  WiFi.begin(ssid, password);
  Serial.print("\nConnecting to "); Serial.println(ssid);
  uint8_t i = 0;
  while (WiFi.status() != WL_CONNECTED && i++ < 20) delay(500);
  if (i == 21) {
    Serial.print("Could not connect to"); Serial.println(ssid);
    while (1) delay(500);
  }
  Serial.print("Ready! Use ");
  Serial.print(WiFi.localIP());
  Serial.println(" to access client");

  M5.dis.drawpix(0, 0x00ff00);  //red
  M5.dis.drawpix(0, 0x00ff00);  //red
}

void servo_set()
{
  for (int i = 0; i <= 11; i++) {
    target_angle[i] = 1000 * (TARGET_JOINT_POSITIONS[i] + TRIM[i]);
    SrvAng[i] = map(target_angle[i], cont_min, cont_max, SERVOMIN, SERVOMAX); //angle（-1.57～1.57rad）-> pulse width（150～500）
    pwm.setPWM(i, 0, SrvAng[i]);
  }
}

void angle_init()
{
  //initail_count 分だけ捨てる
  for (int j = 1; j < initial_count; j++) {
    M5.IMU.getAhrsData(&pitch, &roll, &yaw);
    delay(10);
  }
  
  //initail_count 分だけ初期値として平均値を求める
  for (int i = 1; i <= initial_count; i++) {
    M5.IMU.getAhrsData(&pitch, &roll, &yaw);
    pitch_initial += pitch;
    roll_initial += roll;
    yaw_initial += yaw;
    delay(10);
  }
  pitch_initial /= initial_count;
  roll_initial /= initial_count;
  yaw_initial /= initial_count;
}

void setup()
{
  Serial.begin(19200);
  // void M5Atom::begin(bool SerialEnable , bool I2CEnable , bool DisplayEnable )
  M5.begin(true, false, true);

  pinMode(echo,INPUT); //Sonic Sensor echo
  pinMode(trig,OUTPUT); //Sonic Sensor triger

  setupWiFi();

  Wire.begin(19, 22); //SDA-19, SCL-22

  pwm.begin();                   //initial setting (for 0x40) (PCA9685)
  pwm.setPWMFreq(50);            //PWM 50Hz (for 0x40) (PCA9685)

  servo_set();

  M5.dis.drawpix(0, 0x0000ff);  //blue
  M5.dis.drawpix(0, 0x0000ff);  //blue

  Serial.println("Waiting for connections...");

  IMU_Distance_data.data_length = 4;
  IMU_Distance_data.data = (int32_t *)malloc(sizeof(int32_t) * 3);

  M5.IMU.Init();
  M5.IMU.SetGyroFsr(IMU_GFS);
  M5.IMU.SetAccelFsr(IMU_AFS);

  nh.initNode();
  nh.subscribe(sub);
  nh.advertise(IMU_Distance_chatter);

  M5.dis.drawpix(0, 0xff0000); //green
  M5.dis.drawpix(0, 0xff0000); //green

  angle_init();

  for (uint32_t i = 0; i < 25; i++) {
    M5.dis.drawpix(i, 0xff0000); //green
  }

  xTaskCreatePinnedToCore(IMU_Distance_get, "IMU_Distance_get", 4096, NULL, 5, NULL, 1);
}

void IMU_Distance_get(void *pvParameters)
{
  while(1){
    M5.IMU.getAhrsData(&pitch, &roll, &yaw);
    pitch = pitch - pitch_initial;
    roll = roll - roll_initial;
    yaw = yaw - yaw_initial;

    digitalWrite(trig,HIGH); //超音波を出力
    delayMicroseconds(10); //10μsパルスを出す
    digitalWrite(trig,LOW);
    Duration = pulseIn(echo,HIGH); //センサからパルス間隔を取得
    if (Duration > 0) {
      Distance = Duration/5.77; // パルス間隔から距離を計算 mm
      if (Distance > 500)
      {
        Distance = 500;
      }
    }
    
    Serial.printf("pitch:%.2f,roll:%.2f,yaw:%.2f,Distance:%.2f\r\n", pitch, roll, yaw, Distance);
    IMU_Distance_data.data[0] = int(pitch);
    IMU_Distance_data.data[1] = int(roll);
    IMU_Distance_data.data[2] = int(yaw);
    IMU_Distance_data.data[3] = int(Distance);
    IMU_Distance_chatter.publish( &IMU_Distance_data );
    delay(200);
  }
}

void loop()
{
  nh.spinOnce();
  delay(1);
}

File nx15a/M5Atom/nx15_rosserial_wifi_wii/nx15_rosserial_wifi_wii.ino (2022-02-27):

// wii nunchuck adapter is based on https://github.com/todbot/wiichuck_adapter.git
#include "M5Atom.h"
#include <Wire.h>
#include <ros.h>
#include <std_msgs/Int32MultiArray.h>
#include <WiFi.h>

int loop_cnt=0;

static uint8_t nunchuck_buf[6];   // array to store nunchuck data,

WiFiClient client;
IPAddress server(192, 168, 10, 19); //ROS core IP adress

const char* ssid = "XXXXXXXXXXXXX";
const char* password = "XXXXXXXXXXXXX";

// initialize the I2C system, join the I2C bus,and tell the nunchuck we're talking to it
static void nunchuck_init()
{ 
    Wire.begin(19, 22);                // join i2c bus as master; for M5Atom SDA-19, SCL-22
    Wire.beginTransmission(0x52);// transmit to device 0x52
    Wire.write((uint8_t)0x40);// sends memory address
    Wire.write((uint8_t)0x00);// sends sent a zero.  
    Wire.endTransmission();// stop transmitting
}

// Send a request for data to the nunchuck was "send_zero()"
static void nunchuck_send_request()
{
    Wire.beginTransmission(0x52);// transmit to device 0x52

    Wire.write((uint8_t)0x00);// sends one byte

    Wire.endTransmission();// stop transmitting
}

// Encode data to format that most wiimote drivers except only needed if you use one of the regular wiimote drivers
static char nunchuk_decode_byte (char x)
{
    x = (x ^ 0x17) + 0x17;
    return x;
}

// Receive data back from the nunchuck, returns 1 on successful read. returns 0 on failure
static int nunchuck_get_data()
{
    int cnt=0;
    Wire.requestFrom (0x52, 6);// request data from nunchuck
    while (Wire.available ()) {
        // receive byte as an integer
        nunchuck_buf[cnt] = nunchuk_decode_byte( Wire.read() );
        cnt++;
    }
    nunchuck_send_request();  // send request for next data payload
    // If we recieved the 6 bytes, then go print them
    if (cnt >= 5) {
        return 1;   // success
    }
    return 0; //failure
}

// returns zbutton state: 1=pressed, 0=notpressed
static int nunchuck_zbutton()
{
    return ((nunchuck_buf[5] >> 0) & 1) ? 0 : 1;  // voodoo
}

// returns zbutton state: 1=pressed, 0=notpressed
static int nunchuck_cbutton()
{
    return ((nunchuck_buf[5] >> 1) & 1) ? 0 : 1;  // voodoo
}

// returns value of x-axis joystick
static int nunchuck_joyx()
{
    return nunchuck_buf[0]; 
}

// returns value of y-axis joystick
static int nunchuck_joyy()
{
    return nunchuck_buf[1];
}

// returns value of x-axis accelerometer
static int nunchuck_accelx()
{
    return nunchuck_buf[2];   // FIXME: this leaves out 2-bits of the data
}

// returns value of y-axis accelerometer
static int nunchuck_accely()
{
    return nunchuck_buf[3];   // FIXME: this leaves out 2-bits of the data
}

// returns value of z-axis accelerometer
static int nunchuck_accelz()
{
    return nunchuck_buf[4];   // FIXME: this leaves out 2-bits of the data
}

class WiFiHardware {
  public:
    WiFiHardware() {};
    void init() {
      client.connect(server, 11412);   
    }
    int read() {
      return client.read();      
    }
    void write(uint8_t* data, int length) {
      for (int i = 0; i < length; i++)
        client.write(data[i]);
    }
    unsigned long time() {
      return millis(); // easy; did this one for you
    }
};

ros::NodeHandle_<WiFiHardware> nh;

std_msgs::Int32MultiArray Wii_joy;

ros::Publisher chatter("Wii_joystick", &Wii_joy);

void setupWiFi() {
  WiFi.begin(ssid, password);
  Serial.print("\nConnecting to "); Serial.println(ssid);
  uint8_t i = 0;
  while (WiFi.status() != WL_CONNECTED && i++ < 20) delay(500);
  if (i == 21) {
    Serial.print("Could not connect to"); Serial.println(ssid);
    while (1) delay(500);
  }
  Serial.print("Ready! Use ");
  Serial.print(WiFi.localIP());
  Serial.println(" to access client");

  M5.dis.drawpix(0, 0x00ff00);  //red
  M5.dis.drawpix(0, 0x00ff00);  //red
}

void setup()
{
    Serial.begin(19200);
    // void M5Atom::begin(bool SerialEnable , bool I2CEnable , bool DisplayEnable )
    M5.begin(true, false, true);
    
    //nunchuck_setpowerpins();
    nunchuck_init(); // send the initilization handshake
    
    setupWiFi();

    Serial.println("Waiting for connections...");

    Wii_joy.data_length = 4;
    Wii_joy.data = (int32_t *)malloc(sizeof(int32_t)*3);
  
    nh.initNode();
    nh.advertise(chatter);

    M5.dis.drawpix(0, 0xff0000); //green
}

void loop()
{
    nunchuck_get_data();

    int zbut = nunchuck_zbutton();
    int cbut = nunchuck_cbutton(); 
    int joyx = map(nunchuck_joyx(),23,225,-15,15);
    if(abs(joyx)<=1) joyx=0;
    int joyy = map(nunchuck_joyy(),20,221,-15,15);
    if(abs(joyy)<=1) joyy=0;

    Serial.print(" zbut: "); Serial.print(zbut);
    Serial.print(" cbut: "); Serial.print(cbut);
    Serial.print(" joyx: "); Serial.print(joyx);
    Serial.print(" joyy: "); Serial.println(joyy);

    Wii_joy.data[0] = zbut;
    Wii_joy.data[1] = cbut;
    Wii_joy.data[2] = joyx;
    Wii_joy.data[3] = joyy;

    chatter.publish( &Wii_joy );
  
    nh.spinOnce();

    delay(50);
}
